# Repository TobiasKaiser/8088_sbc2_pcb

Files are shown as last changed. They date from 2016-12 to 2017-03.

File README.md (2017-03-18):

8088_scb2
========

See [my website][1] for more information on this PCB.

Firmware
--------

The corresponding firmware can be found in the [8088_sbc2_firmware][2] repository.

License
-------

* FT232RL component comes from a [component collection][3] from Werner Almesberger: 

Everything else:

Copyright (c) 2016 Tobias Kaiser <mail@tb-kaiser.de>

Permission is hereby granted, free of charge, to any person obtaining a copy of this hardware, software, and associated documentation files (the "Product"), to deal in the Product without restriction, including without limitation the rights to use, copy, modify, merge, publish, distribute, sublicense, and/or sell copies of the Product, and to permit persons to whom the Product is furnished to do so, subject to the following conditions:

The above copyright notice and this permission notice shall be included in all copies or substantial portions of the Product.

THE PRODUCT IS PROVIDED "AS IS", WITHOUT WARRANTY OF ANY KIND, EXPRESS OR IMPLIED, INCLUDING BUT NOT LIMITED TO THE WARRANTIES OF MERCHANTABILITY, FITNESS FOR A PARTICULAR PURPOSE AND NONINFRINGEMENT. IN NO EVENT SHALL THE AUTHORS OR COPYRIGHT HOLDERS BE LIABLE FOR ANY CLAIM, DAMAGES OR OTHER LIABILITY, WHETHER IN AN ACTION OF CONTRACT, TORT OR OTHERWISE, ARISING FROM, OUT OF OR IN CONNECTION WITH THE PRODUCT OR THE USE OR OTHER DEALINGS IN THE PRODUCT.

[1]: http://www.tb-kaiser.de/pcbs/8088_sbc2_2016_12_22/
[2]: https://github.com/TobiasKaiser/8088_sbc2_firmware/
[3]: http://projects.qi-hardware.com/index.php/p/kicad-libs/source/tree/master/components/ft232rl.lib

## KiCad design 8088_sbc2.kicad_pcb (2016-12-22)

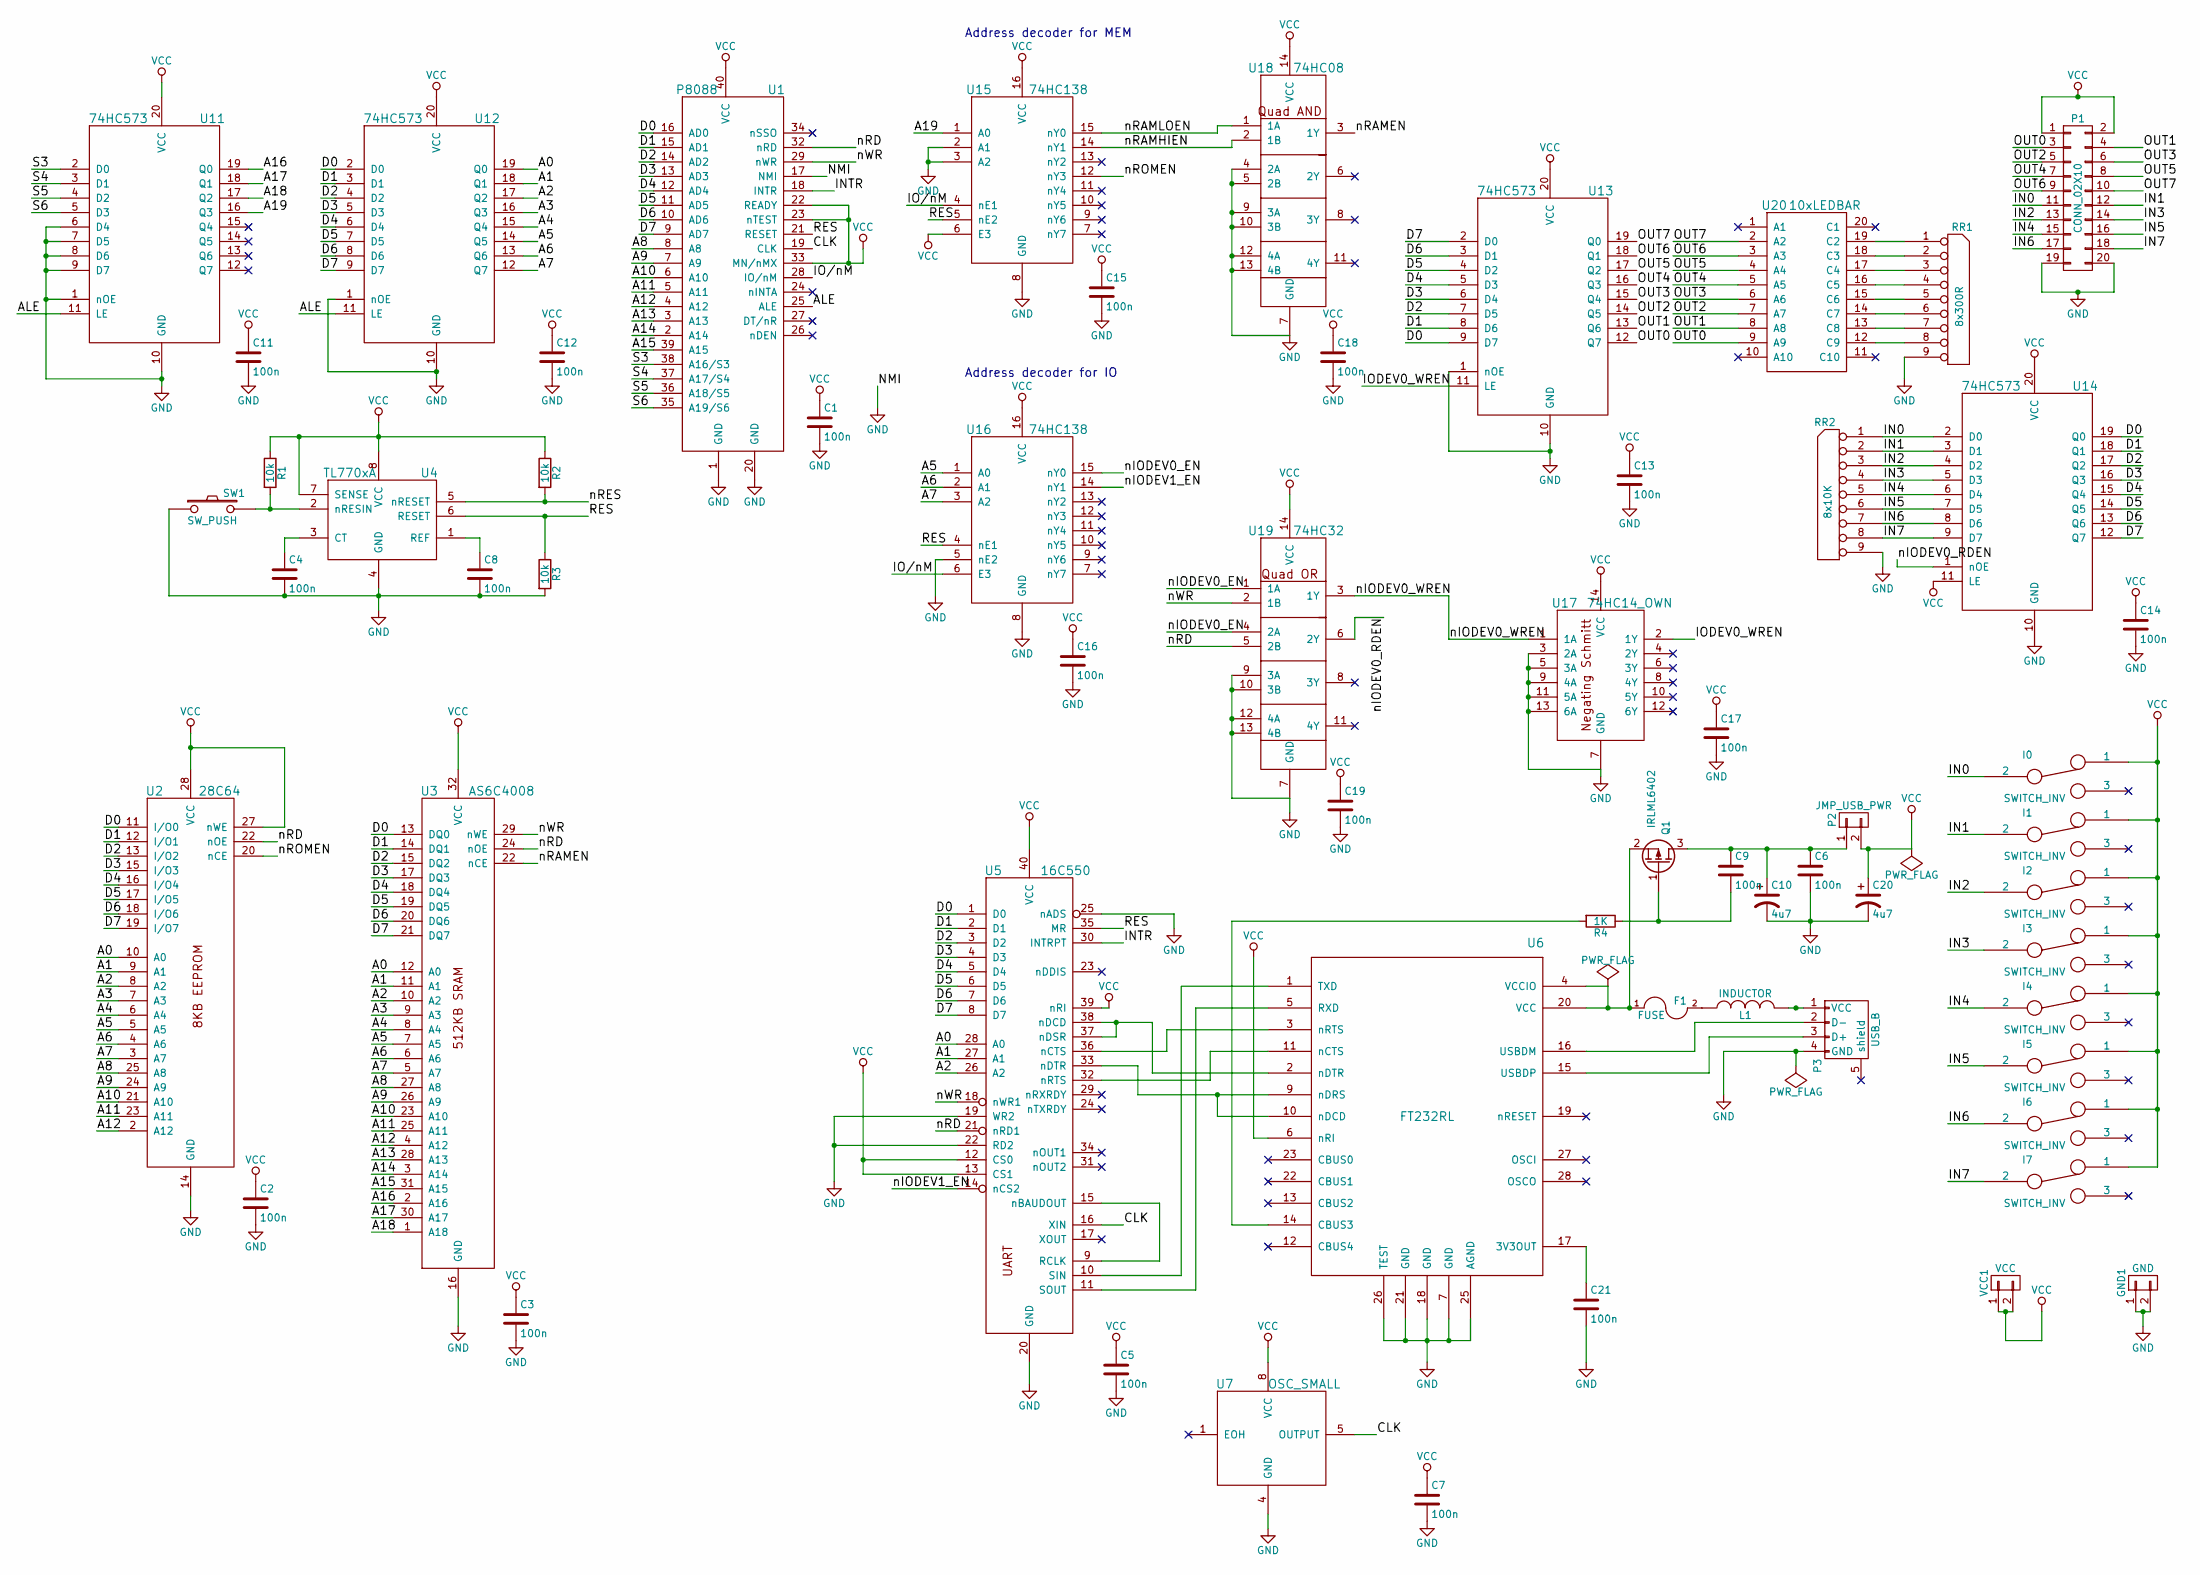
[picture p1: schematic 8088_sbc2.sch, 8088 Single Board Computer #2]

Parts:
C1, C2, C3, C4, C5, C6, C7, C8, C9, C11, C12, C13, C14, C15, C16, C17, C18, C19, C21: 100n; C_Disc_D3_P2.5
C10: 4u7; C_Radial_D6.3_L11.2_P2.5
C20: 4u7; C_Radial_D7.5_L11.2_P2.5
F1: FUSE; C_1206_HandSoldering
GND1: GND; Pin_Header_Straight_1x02
I0, I1, I2, I3, I4, I5, I6, I7: SWITCH_INV; EG1218
L1: INDUCTOR; C_0805_HandSoldering
P1: CONN_02X10; Pin_Header_Straight_2x10
P2: JMP_USB_PWR; Pin_Header_Straight_1x02
P3: USB_B
Q1: IRLML6402; SOT-23_Handsoldering
R1, R2, R3: 10k; Resistor_Horizontal_RM7mm
R4: 1K; R_0805_HandSoldering
RR1: 8x300R; Pin_Header_Straight_1x09
RR2: 8x10K; Pin_Header_Straight_1x09
SW1: SW_PUSH; SW_PUSH_6mm
U1: P8088; DIP-40_W15.24mm
U2: 28C64; DIP-28_W15.24mm
U3: AS6C4008; DIP-32_W15.24mm
U4: TL770xA; DIP-8_W7.62mm
U5: 16C550; DIP-40_W15.24mm
U6: FT232RL; SSOP-28_5.3x10.2mm_Pitch0.65mm
U7: OSC_SMALL; DIP-8_W7.62mm
U11, U12, U13, U14: 74HC573; DIP-20_W7.62mm
U15, U16: 74HC138; DIP-16_W7.62mm
U17: 74HC14_OWN; DIP-14_W7.62mm
U18: 74HC08; DIP-14_W7.62mm
U19: 74HC32; DIP-14_W7.62mm
U20: 10xLEDBAR; DIP-20_W7.62mm
VCC1: VCC; Pin_Header_Straight_1x02

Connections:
/A0: U2.10 (A0), U3.12 (A0), U5.28 (A0), U12.19 (Q0)
/A1: U2.9 (A1), U3.11 (A1), U5.27 (A1), U12.18 (Q1)
/A2: U2.8 (A2), U3.10 (A2), U5.26 (A2), U12.17 (Q2)
/A3: U2.7 (A3), U3.9 (A3), U12.16 (Q3)
/A4: U2.6 (A4), U3.8 (A4), U12.15 (Q4)
/A5: U2.5 (A5), U3.7 (A5), U12.14 (Q5), U16.1 (A0)
/A6: U2.4 (A6), U3.6 (A6), U12.13 (Q6), U16.2 (A1)
/A7: U2.3 (A7), U3.5 (A7), U12.12 (Q7), U16.3 (A2)
/A8: U1.8 (A8), U2.25 (A8), U3.27 (A8)
/A9: U1.7 (A9), U2.24 (A9), U3.26 (A9)
/A10: U1.6 (A10), U2.21 (A10), U3.23 (A10)
/A11: U1.5 (A11), U2.23 (A11), U3.25 (A11)
/A12: U1.4 (A12), U2.2 (A12), U3.4 (A12)
/A13: U1.3 (A13), U3.28 (A13)
/A14: U1.2 (A14), U3.3 (A14)
/A15: U1.39 (A15), U3.31 (A15)
/A16: U3.2 (A16), U11.19 (Q0)
/A17: U3.30 (A17), U11.18 (Q1)
/A18: U3.1 (A18), U11.17 (Q2)
/A19: U11.16 (Q3), U15.1 (A0)
/ALE: U1.25 (ALE), U11.11 (LE), U12.11 (LE)
/CLK: U1.19 (CLK), U5.16 (XIN), U7.5 (OUTPUT)
/D0: U1.16 (AD0), U2.11 (I/O0), U3.13 (DQ0), U5.1 (D0), U12.2 (D0), U13.9 (D7), U14.19 (Q0)
/D1: U1.15 (AD1), U2.12 (I/O1), U3.14 (DQ1), U5.2 (D1), U12.3 (D1), U13.8 (D6), U14.18 (Q1)
/D2: U1.14 (AD2), U2.13 (I/O2), U3.15 (DQ2), U5.3 (D2), U12.4 (D2), U13.7 (D5), U14.17 (Q2)
/D3: U1.13 (AD3), U2.15 (I/O3), U3.17 (DQ3), U5.4 (D3), U12.5 (D3), U13.6 (D4), U14.16 (Q3)
/D4: U1.12 (AD4), U2.16 (I/O4), U3.18 (DQ4), U5.5 (D4), U12.6 (D4), U13.5 (D3), U14.15 (Q4)
/D5: U1.11 (AD5), U2.17 (I/O5), U3.19 (DQ5), U5.6 (D5), U12.7 (D5), U13.4 (D2), U14.14 (Q5)
/D6: U1.10 (AD6), U2.18 (I/O6), U3.20 (DQ6), U5.7 (D6), U12.8 (D6), U13.3 (D1), U14.13 (Q6)
/D7: U1.9 (AD7), U2.19 (I/O7), U3.21 (DQ7), U5.8 (D7), U12.9 (D7), U13.2 (D0), U14.12 (Q7)
/IN0: I0.2, P1.11, RR2.1 (COM), U14.2 (D0)
/IN1: I1.2, P1.12, RR2.2, U14.3 (D1)
/IN2: I2.2, P1.13, RR2.3, U14.4 (D2)
/IN3: I3.2, P1.14, RR2.4, U14.5 (D3)
/IN4: I4.2, P1.15, RR2.5, U14.6 (D4)
/IN5: I5.2, P1.16, RR2.6, U14.7 (D5)
/IN6: I6.2, P1.17, RR2.7, U14.8 (D6)
/IN7: I7.2, P1.18, RR2.8, U14.9 (D7)
/INTR: U1.18 (INTR), U5.30 (INTRPT)
/IO/nM: U1.28 (IO/nM), U15.4 (nE1), U16.6 (E3)
/IODEV0_WREN: U13.11 (LE), U17.2 (1Y)
/OUT0: P1.3, U13.12 (Q7), U20.9 (A9)
/OUT1: P1.4, U13.13 (Q6), U20.8 (A8)
/OUT2: P1.5, U13.14 (Q5), U20.7 (A7)
/OUT3: P1.6, U13.15 (Q4), U20.6 (A6)
/OUT4: P1.7, U13.16 (Q3), U20.5 (A5)
/OUT5: P1.8, U13.17 (Q2), U20.4 (A4)
/OUT6: P1.9, U13.18 (Q1), U20.3 (A3)
/OUT7: P1.10, U13.19 (Q0), U20.2 (A2)
/RES: R3.1, U1.21 (RESET), U4.6 (RESET), U5.35 (MR), U15.5 (nE2), U16.4 (nE1)
/S3: U1.38 (A16/S3), U11.2 (D0)
/S4: U1.37 (A17/S4), U11.3 (D1)
/S5: U1.36 (A18/S5), U11.4 (D2)
/S6: U1.35 (A19/S6), U11.5 (D3)
/nFRAMEN: U15.13 (nY2)
/nIODEV0_EN: U16.15 (nY0), U19.1 (1A), U19.4 (2A)
/nIODEV0_RDEN: U14.1 (nOE), U19.6 (2Y)
/nIODEV0_WREN: U17.1 (1A), U19.3 (1Y)
/nIODEV1_EN: U5.14 (nCS2), U16.14 (nY1)
/nRAMEN: U3.22 (nCE), U18.3 (1Y)
/nRAMHIEN: U15.14 (nY1), U18.2 (1B)
/nRAMLOEN: U15.15 (nY0), U18.1 (1A)
/nRD: U1.32 (nRD), U2.22 (nOE), U3.24 (nOE), U5.21 (nRD1), U19.5 (2B)
/nRES: R2.2, U4.5 (nRESET)
/nROMEN: U2.20 (nCE), U15.12 (nY3)
/nWR: U1.29 (nWR), U3.29 (nWE), U5.18 (nWR1), U19.2 (1B)
GND: C1.2, C2.2, C3.2, C4.2, C5.2, C6.2, C7.2, C8.2, C10.2, C11.2, C12.2, C13.2, C14.2, C15.2, C16.2, C17.2, C18.2, C19.2, C20.2, C21.2, GND1.1, GND1.2, P1.19, P1.20, P3.4 (GND), R3.2, RR1.9, RR2.9, SW1.1, U1.1 (GND), U1.17 (NMI), U1.20 (GND), U2.14 (GND), U3.16 (GND), U4.4 (GND), U5.19 (WR2), U5.20 (GND), U5.22 (RD2), U5.25 (nADS), U6.7 (GND), U6.18 (GND), U6.21 (GND), U6.25 (AGND), U6.26 (TEST), U7.4 (GND), U11.1 (nOE), U11.6 (D4), U11.7 (D5), U11.8 (D6), U11.9 (D7), U11.10 (GND), U12.1 (nOE), U12.10 (GND), U13.1 (nOE), U13.10 (GND), U14.10 (GND), U15.2 (A1), U15.3 (A2), U15.8 (GND), U16.5 (nE2), U16.8 (GND), U17.3 (2A), U17.5 (3A), U17.7 (GND), U17.9 (4A), U17.11 (5A), U17.13 (6A), U18.4 (2A), U18.5 (2B), U18.7 (GND), U18.9 (3A), U18.10 (3B), U18.12 (4A), U18.13 (4B), U19.7 (GND), U19.9 (3A), U19.10 (3B), U19.12 (4A), U19.13 (4B)
unnamed: C4.1, U4.3 (CT)
unnamed: C8.1, U4.1 (REF)
unnamed: C9.2, Q1.1 (G), R4.1
unnamed: C6.1, C9.1, C10.1, P2.1, Q1.3 (D)
unnamed: C21.1, U6.17 (3V3OUT)
unnamed: F1.1, Q1.2 (S), U6.4 (VCCIO), U6.20 (VCC)
unnamed: F1.2, L1.1
unnamed: L1.2, P3.1 (VCC)
unnamed: P3.2 (D-), U6.16 (USBDM)
unnamed: P3.3 (D+), U6.15 (USBDP)
unnamed: R1.2, SW1.2, U4.2 (nRESIN)
unnamed: R4.2, U6.14 (CBUS3)
unnamed: RR1.1 (COM), U20.19 (C2)
unnamed: RR1.2, U20.18 (C3)
unnamed: RR1.3, U20.17 (C4)
unnamed: RR1.4, U20.16 (C5)
unnamed: RR1.5, U20.15 (C6)
unnamed: RR1.6, U20.14 (C7)
unnamed: RR1.7, U20.13 (C8)
unnamed: RR1.8, U20.12 (C9)
unnamed: U5.10 (SIN), U6.1 (TXD)
unnamed: U5.11 (SOUT), U6.5 (RXD)
unnamed: U5.9 (RCLK), U5.15 (nBAUDOUT)
unnamed: U5.32 (nRTS), U6.11 (nCTS)
unnamed: U5.33 (nDTR), U6.9 (nDRS), U6.10 (nDCD)
unnamed: U5.36 (nCTS), U6.3 (nRTS)
unnamed: U5.37 (nDSR), U5.38 (nDCD), U6.2 (nDTR)
VCC: C1.1, C2.1, C3.1, C5.1, C7.1, C11.1, C12.1, C13.1, C14.1, C15.1, C16.1, C17.1, C18.1, C19.1, C20.1, I0.1, I1.1, I2.1, I3.1, I4.1, I5.1, I6.1, I7.1, P1.1, P1.2, P2.2, R1.1, R2.1, U1.22 (READY), U1.23 (nTEST), U1.33 (MN/nMX), U1.40 (VCC), U2.27 (nWE), U2.28 (VCC), U3.32 (VCC), U4.7 (SENSE), U4.8 (VCC), U5.12 (CS0), U5.13 (CS1), U5.39 (nRI), U5.40 (VCC), U6.6 (nRI), U7.8 (VCC), U11.20 (VCC), U12.20 (VCC), U13.20 (VCC), U14.11 (LE), U14.20 (VCC), U15.6 (E3), U15.16 (VCC), U16.16 (VCC), U17.14 (VCC), U18.14 (VCC), U19.14 (VCC), VCC1.1, VCC1.2

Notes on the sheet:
Address decoder for MEM
Address decoder for IO

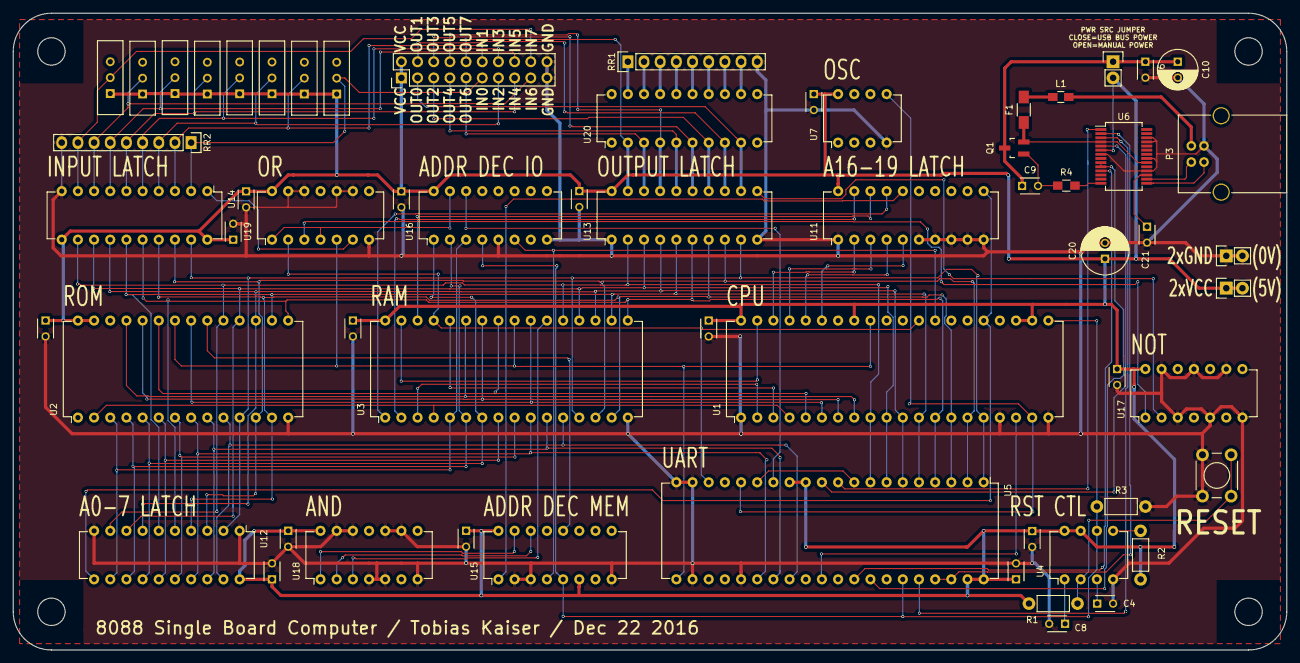
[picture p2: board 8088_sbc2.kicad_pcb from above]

Board: 2 copper layers, 200.0 x 100.0 mm, 61 parts (0 on the bottom side), 94 nets.

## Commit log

2016-10-12 working on schematic
    [8088_sbc2.sch]
2016-10-21 am schaltplan weitergearbeitet
    [8088_sbc2.sch]
2016-10-28 schematic erc good.
    [8088_sbc2.sch]
2016-12-21 looks good :D
    [8088_sbc2.kicad_pcb, 8088_sbc2.sch]
2016-12-22 version with new design rules
    [8088_sbc2.kicad_pcb]
2016-12-22 shitty kicad fucked it up while saving. fuck it.
    [8088_sbc2.kicad_pcb]
2016-12-22 DRC w/ cheaper tolerances successful
    [8088_sbc2.kicad_pcb]
2016-12-22 almost ready for submission
    [8088_sbc2.kicad_pcb]
2016-12-22 DRC and ERC OK. making some gerbers now?!
    [8088_sbc2.sch]
2016-12-22 Gerber erzeugt, sieht gut aus, wird bald bestellt.
    [8088_sbc2.kicad_pcb]
